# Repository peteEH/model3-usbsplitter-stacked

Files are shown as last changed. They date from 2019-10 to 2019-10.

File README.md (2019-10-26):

# model3-usbsplitter-stacked
stacked usb splitter for model 3, end launch

BOM to get the splitter assembled

Part Number     Quantity    Comments
5787745-2       1           double stacked, type-A, USB receptacle
UP2-AH-1-TH     1           plug, type-A, usb
4.7uF Cap       1           Any capacitor, 0805 package, 10V or higher rating, 1uF to 6.8uF cap range
2 ohm res       1           0805 package, 1.5 to 3 ohms
22uF Cap        1           Any capacitor, 1210 package, 10V or higher rating, 10uF to 47uF cap range

PCB             1           Order PCB from JLC PCB or similar fab house   (QTY 5 for $2 @ JLC)

## LICENSE ##
Hardware License is Creative Commons - Attribution 3.0

Feel free to use these files to learn, explore electronics.

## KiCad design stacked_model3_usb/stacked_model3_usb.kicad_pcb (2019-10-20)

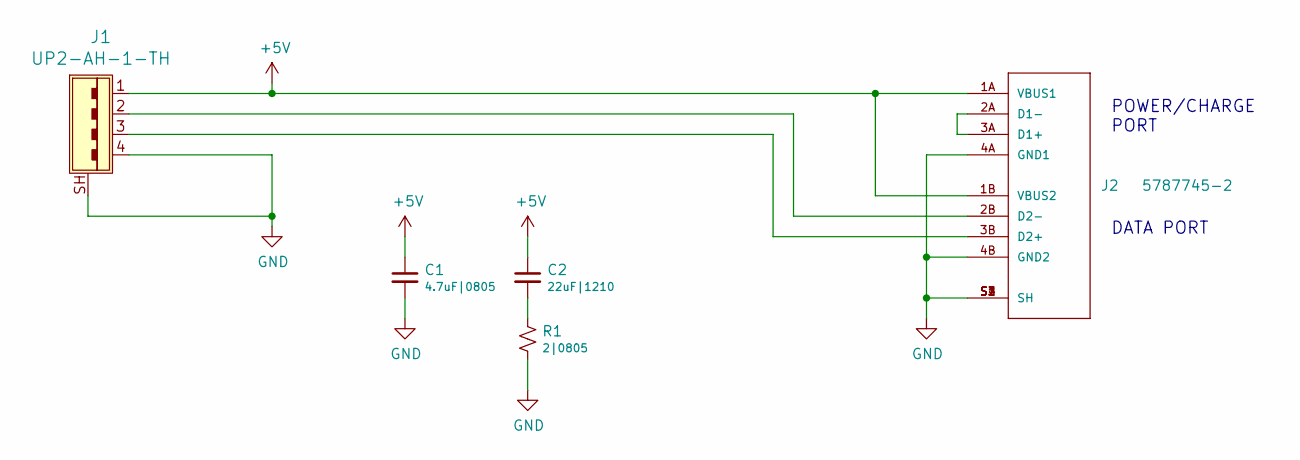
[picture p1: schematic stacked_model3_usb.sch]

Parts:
C1: 4.7uF|0805; C_0805_2012Metric
C2: 22uF|1210; C_1210_3225Metric
J1: UP2-AH-1-TH; USB_Male_A_UP2-AH-1-TH; MPN UP2-AH-1-TH; Digi-Key_PN 102-3996-ND
J2: 5787745-2; TE_5787745-2
R1: 2|0805; R_0805_2012Metric

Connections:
+5V: C1.1, C2.1, J1.1, J2.1A (VBUS1), J2.1B (VBUS2)
GND: C1.2, J1.4, J1.SH, J2.4A (GND1), J2.4B (GND2), J2.S1 (SH), J2.S2 (SH), J2.S3 (SH), J2.S4 (SH), R1.2
unnamed: C2.2, R1.1
unnamed: J1.2, J2.2B (D2-)
unnamed: J1.3, J2.3B (D2+)
unnamed: J2.2A (D1-), J2.3A (D1+)

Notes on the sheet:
DATA PORT
POWER/CHARGE PORT

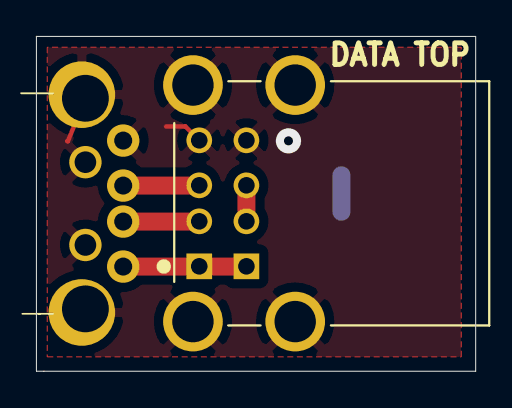
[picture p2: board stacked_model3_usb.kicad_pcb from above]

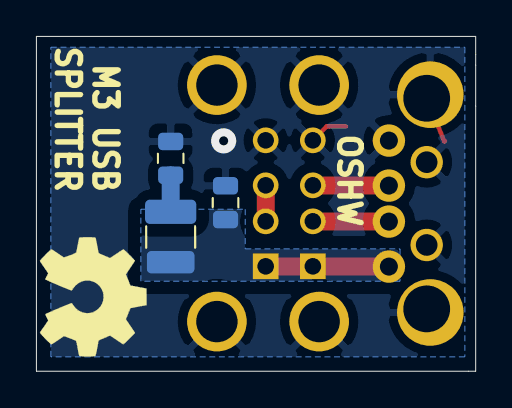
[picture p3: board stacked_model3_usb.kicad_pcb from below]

Board: 2 copper layers, 24.4 x 18.6 mm, 5 parts (3 on the bottom side), 6 nets.

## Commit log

2019-10-20 initial set of files uploaded
    [_saved_stacked_model3_usb.sch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]
2019-10-20 updated readme, added BOM info
